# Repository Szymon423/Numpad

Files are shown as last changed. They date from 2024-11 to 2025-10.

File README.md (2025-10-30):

<div align="center">

# 🔢 Numpad

*A custom-designed numeric keypad project*

</div>

---

## 📖 About

This project is about designing my own Numpad.

> [!NOTE]  
> But not as good as existing solutions

I wanted to do this because I bought a keyboard without a numeric keypad. The project was on my to-do list, waiting until (I make it real) I bought a keyboard with a numeric keypad. Even though I'm the proud owner of a keyboard with a numeric keypad, I wanted to finish it.

---

## 🖼️ Let's have a look

<div align="center">

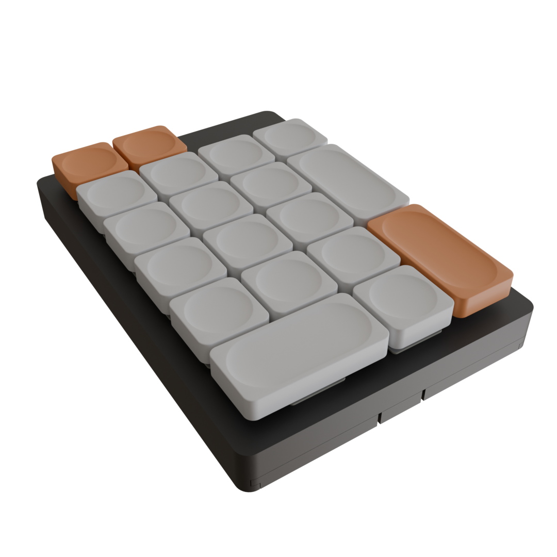
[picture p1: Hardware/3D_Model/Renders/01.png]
Main Render


</div>

---

## 🔧 Hardware

Hardware was designed in **KiCad** around the **RP2040** from Raspberry Pi. I like low-profile keyboards, thus I used **Gateron KS-33** switches with custom keycaps inspired by the **Logitech MX Keys**.

### Additional Renders

<div align="center">

<table>
  <tr>
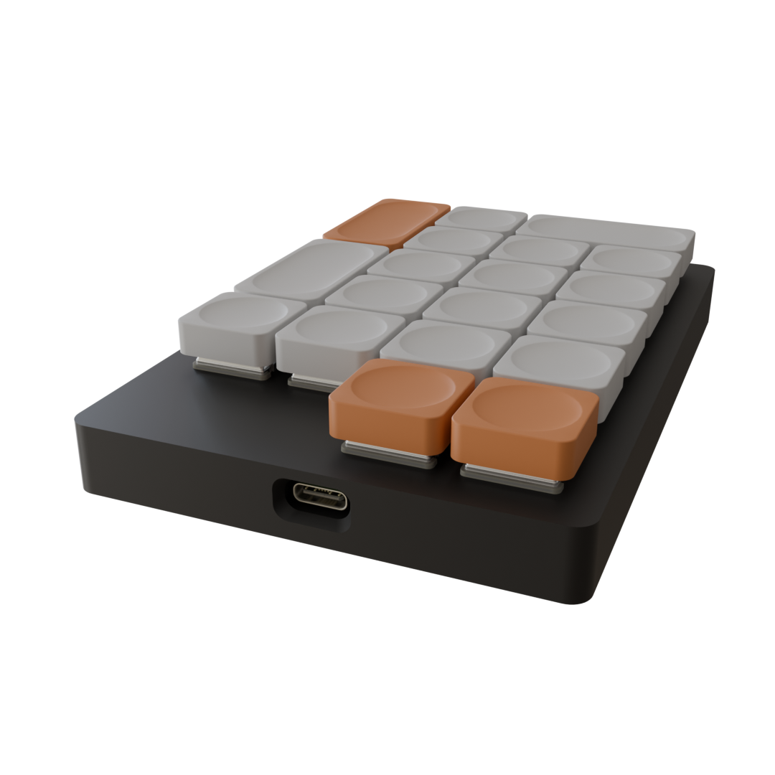
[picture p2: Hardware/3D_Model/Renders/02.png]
Render 02
    <td width="50%"></td>
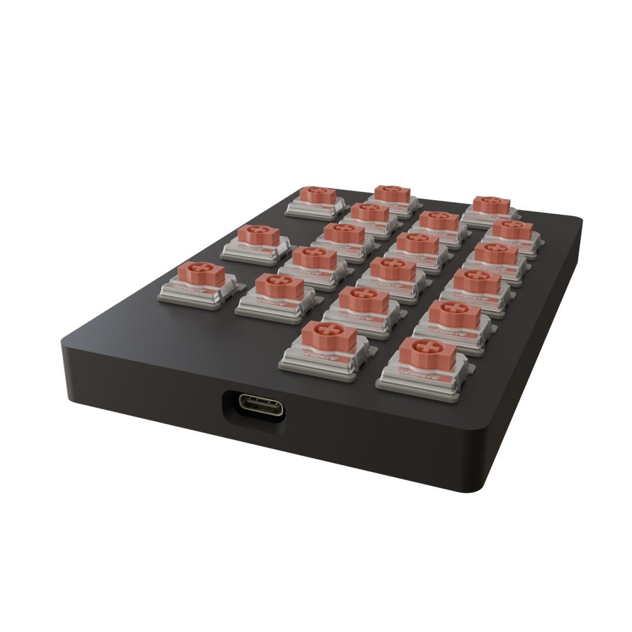
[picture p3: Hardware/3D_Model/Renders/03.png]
Render 03
    <td width="50%"></td>
  </tr>
  <tr>
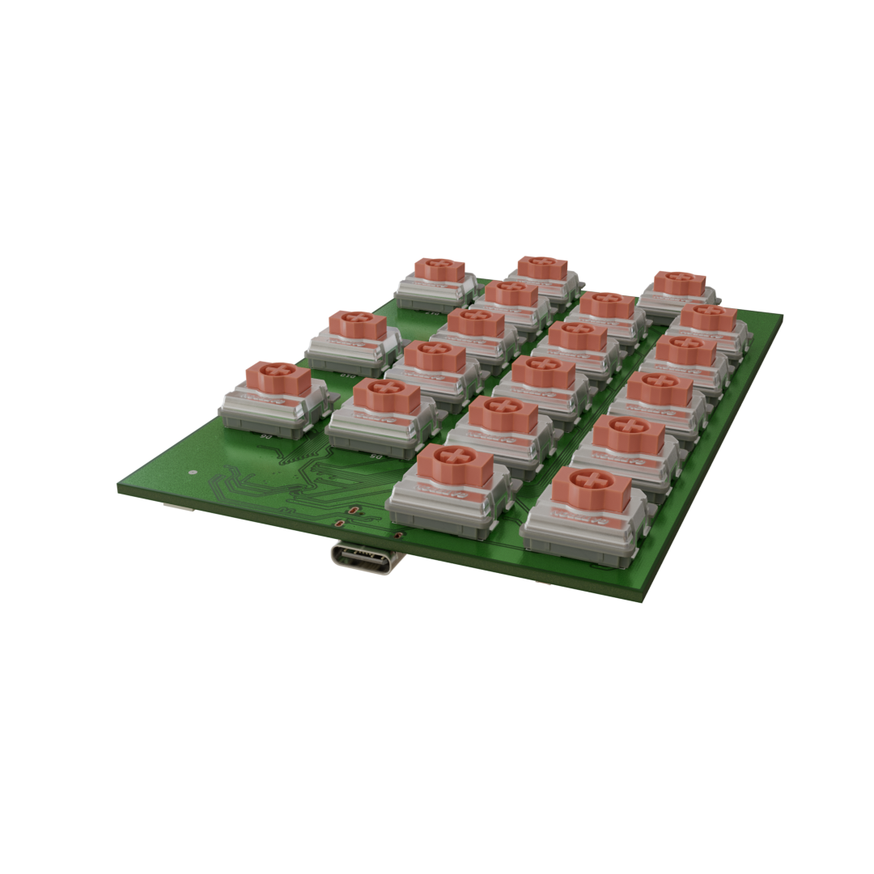
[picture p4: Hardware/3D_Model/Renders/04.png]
Render 04
    <td width="50%"></td>
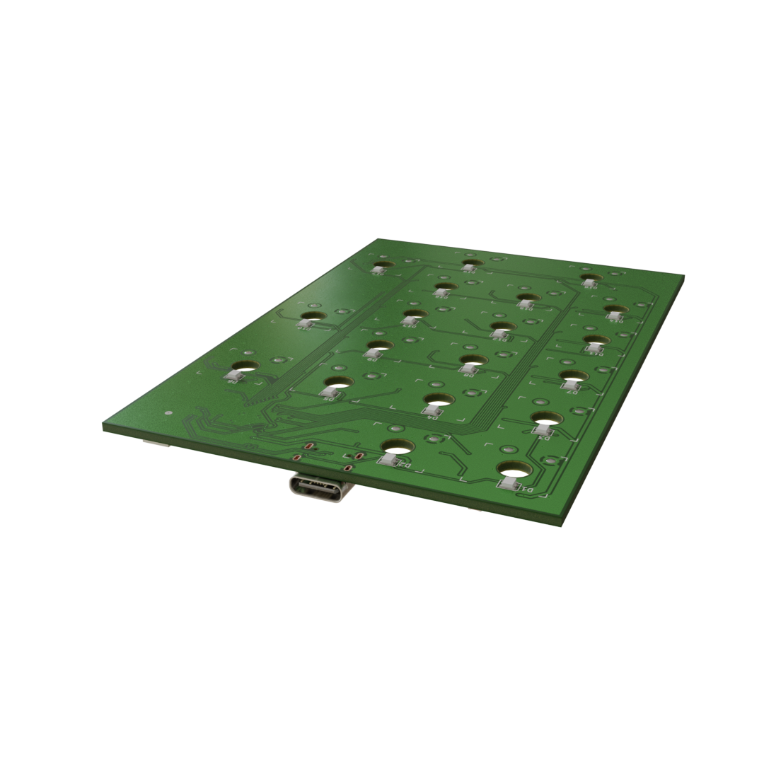
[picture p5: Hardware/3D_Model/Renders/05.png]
Render 05
    <td width="50%"></td>
  </tr>
</table>

</div>

---

## 💻 Software

Software is still in development. 🚧

---

<div align="center">

*Made because of lack of cool and cheap solutions along with ❤️ to tinkering*

</div>

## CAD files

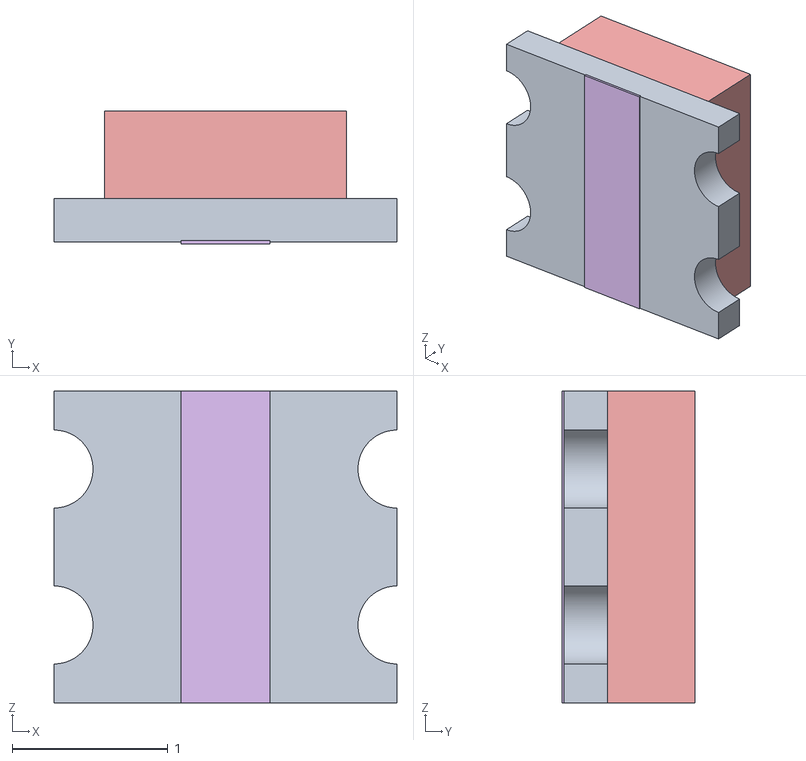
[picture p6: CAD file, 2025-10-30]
Hardware/3D_Model/Assets/WS2812C-2020.obj
2.20 x 0.85 x 2.00
obj1
obj2
obj3
obj4
obj5
obj6
obj7
obj8

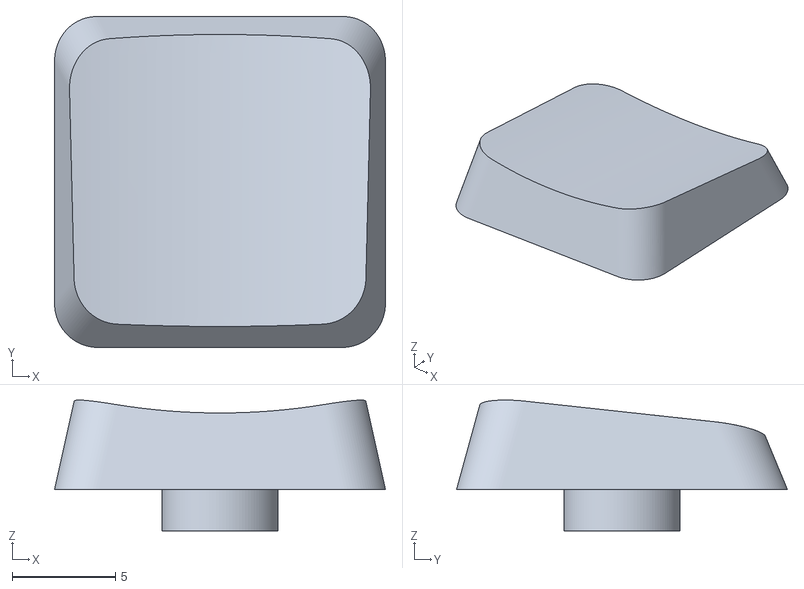
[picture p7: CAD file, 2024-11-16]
Hardware/3D_Model/Assets/Keycap-Low-Profile-Resin.stl
16.0 x 16.0 x 6.33

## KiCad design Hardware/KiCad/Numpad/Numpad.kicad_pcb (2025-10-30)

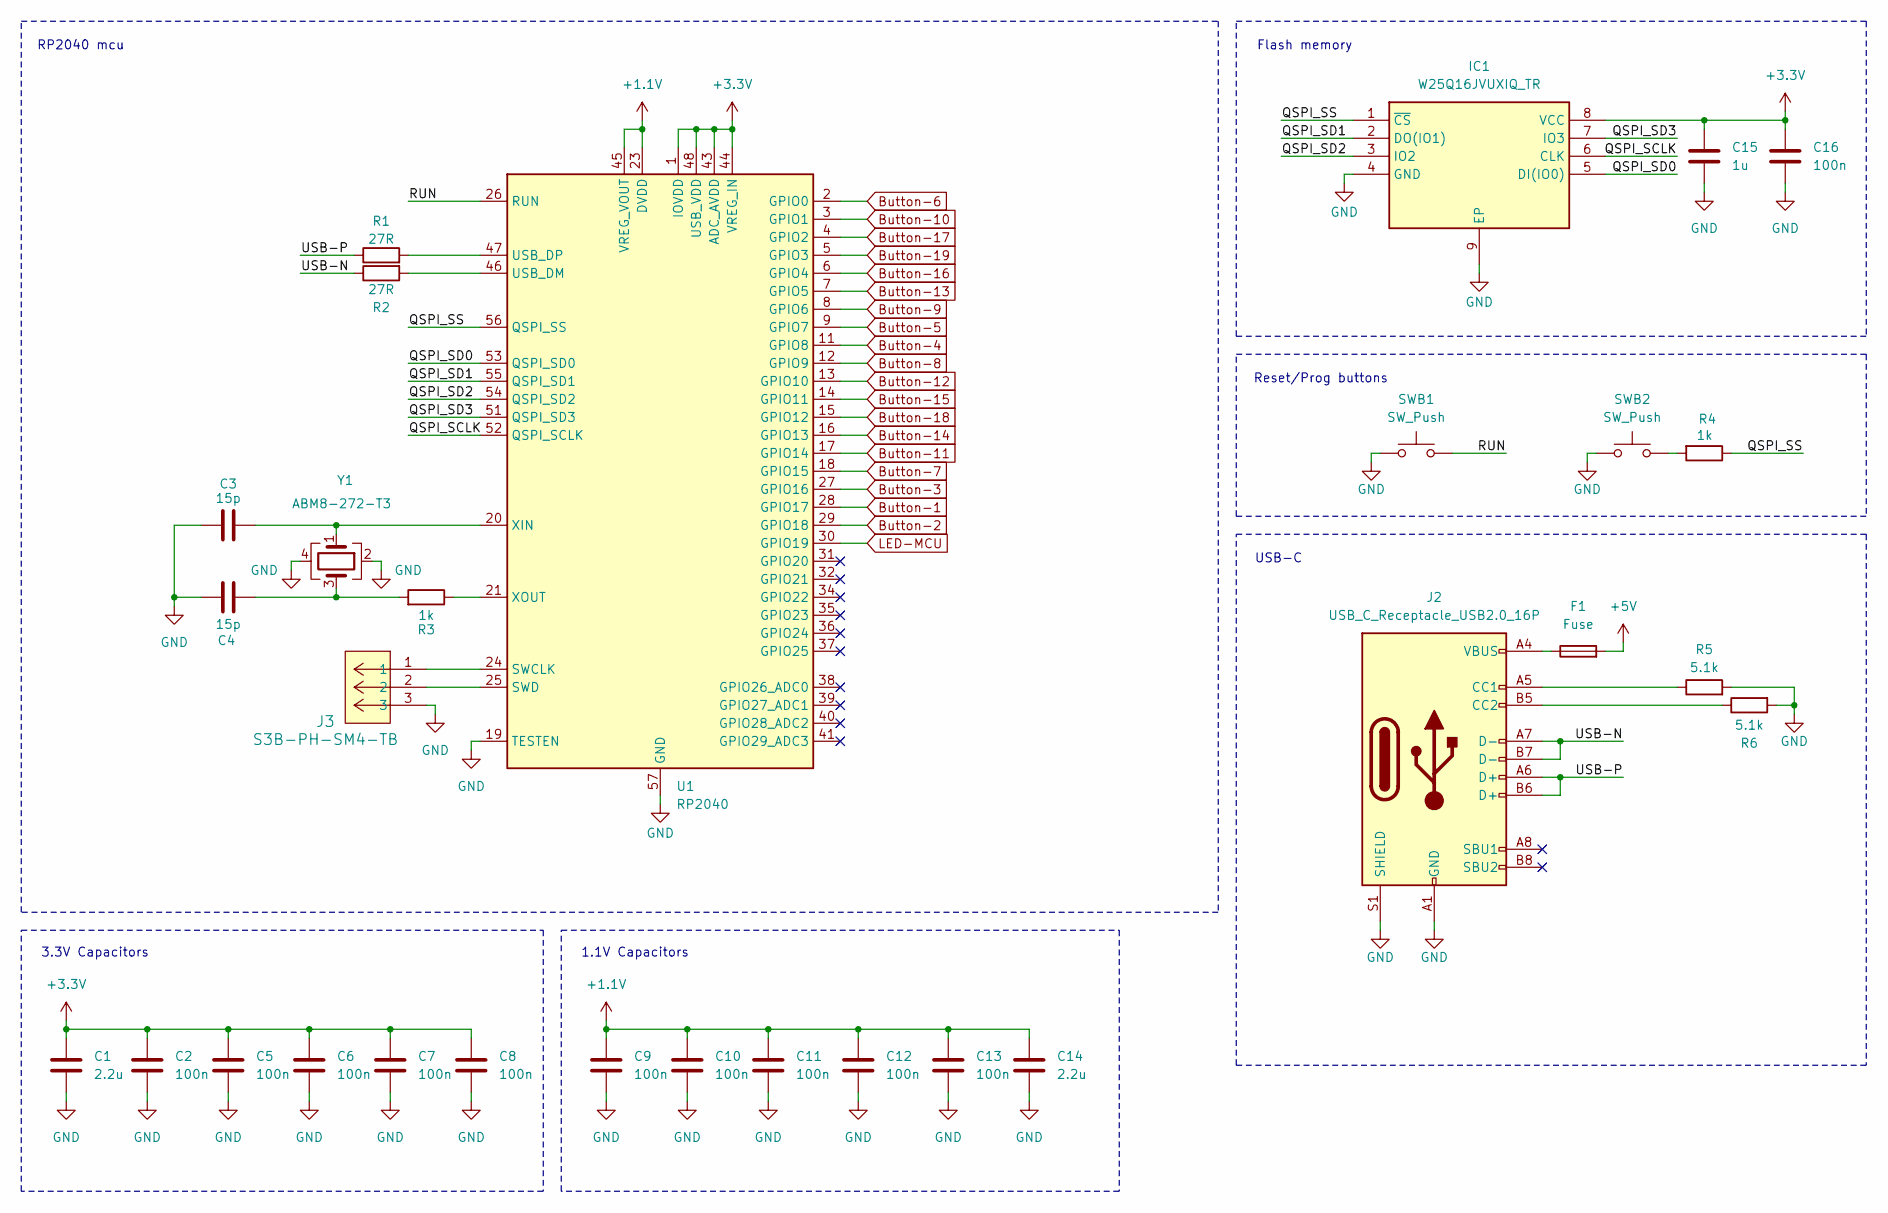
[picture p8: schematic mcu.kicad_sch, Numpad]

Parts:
C1, C14: 2.2u; C_0805_2012Metric
C2, C5, C6, C7, C8, C9, C10, C11, C12, C13, C16: 100n; C_0402_1005Metric
C3, C4: 15p; C_0402_1005Metric
C15: 1u; C_0805_2012Metric
F1: Fuse; Fuse_1206_3216Metric
IC1: W25Q16JVUXIQ_TR; Winbond_USON-8-1EP_3x2mm_P0.5mm_EP0.2x1.6mm; Manufacturer_Part_Number W25Q16JVUXIQ TR
J2: USB_C_Receptacle_USB2.0_16P; USB_C_Receptacle_GCT_USB4105-xx-A_16P_TopMnt_Horizontal
J3: S3B-PH-SM4-TB; CONN3_S3B-PH_JST
R1, R2: 27R; R_0402_1005Metric
R3, R4: 1k; R_0402_1005Metric
R5, R6: 5.1k; R_0603_1608Metric
SWB1, SWB2: SW_Push; SW_Tactile_SPST_NO_Straight_CK_PTS636Sx25SMTRLFS
U1: RP2040; QFN-56-1EP_7x7mm_P0.4mm_EP3.2x3.2mm_ThermalVias
Y1: ABM8-272-T3; Crystal_SMD_Abracon_ABM3B-4Pin_5.0x3.2mm

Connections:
+1.1V: C9.1, C10.1, C11.1, C12.1, C13.1, C14.1, U1.23 (DVDD), U1.45 (VREG_VOUT), U1.50 (DVDD)
+3.3V: C1.1, C2.1, C5.1, C6.1, C7.1, C8.1, C15.1, C16.1, IC1.8 (VCC), U1.1 (IOVDD), U1.10 (IOVDD), U1.22 (IOVDD), U1.33 (IOVDD), U1.42 (IOVDD), U1.43 (ADC_AVDD), U1.44 (VREG_IN), U1.48 (USB_VDD), U1.49 (IOVDD); also elsewhere on the board
+5V: F1.2; also elsewhere on the board
/Microcontroller/QSPI_SCLK: IC1.6 (CLK), U1.52 (QSPI_SCLK)
/Microcontroller/QSPI_SD0: IC1.5 (DI(IO0)), U1.53 (QSPI_SD0)
/Microcontroller/QSPI_SD1: IC1.2 (DO(IO1)), U1.55 (QSPI_SD1)
/Microcontroller/QSPI_SD2: IC1.3 (IO2), U1.54 (QSPI_SD2)
/Microcontroller/QSPI_SD3: IC1.7 (IO3), U1.51 (QSPI_SD3)
/Microcontroller/QSPI_SS: IC1.1 (~CS), R4.1, U1.56 (QSPI_SS)
/Microcontroller/RUN: SWB1.2, U1.26 (RUN)
/Microcontroller/USB-N: J2.A7 (D-), J2.B7 (D-), R2.1
/Microcontroller/USB-P: J2.A6 (D+), J2.B6 (D+), R1.1
Button-1: U1.28 (GPIO17); also elsewhere on the board
Button-2: U1.29 (GPIO18); also elsewhere on the board
Button-3: U1.27 (GPIO16); also elsewhere on the board
Button-4: U1.11 (GPIO8); also elsewhere on the board
Button-5: U1.9 (GPIO7); also elsewhere on the board
Button-6: U1.2 (GPIO0); also elsewhere on the board
Button-7: U1.18 (GPIO15); also elsewhere on the board
Button-8: U1.12 (GPIO9); also elsewhere on the board
Button-9: U1.8 (GPIO6); also elsewhere on the board
Button-10: U1.3 (GPIO1); also elsewhere on the board
Button-11: U1.17 (GPIO14); also elsewhere on the board
Button-12: U1.13 (GPIO10); also elsewhere on the board
Button-13: U1.7 (GPIO5); also elsewhere on the board
Button-14: U1.16 (GPIO13); also elsewhere on the board
Button-15: U1.14 (GPIO11); also elsewhere on the board
Button-16: U1.6 (GPIO4); also elsewhere on the board
Button-17: U1.4 (GPIO2); also elsewhere on the board
Button-18: U1.15 (GPIO12); also elsewhere on the board
Button-19: U1.5 (GPIO3); also elsewhere on the board
GND: C1.2, C2.2, C3.1, C4.1, C5.2, C6.2, C7.2, C8.2, C9.2, C10.2, C11.2, C12.2, C13.2, C14.2, C15.2, C16.2, IC1.4 (GND), IC1.9 (EP), J2.A1 (GND), J2.A12 (GND), J2.B1 (GND), J2.B12 (GND), J2.S1 (SHIELD), J3.3, R5.2, R6.2, SWB1.1, SWB2.1, U1.19 (TESTEN), U1.57 (GND), Y1.2, Y1.4; also elsewhere on the board
LED-MCU: U1.30 (GPIO19); also elsewhere on the board
unnamed: C4.2, R3.2, Y1.3
unnamed: F1.1, J2.A4 (VBUS), J2.A9 (VBUS), J2.B4 (VBUS), J2.B9 (VBUS)
unnamed: J2.A5 (CC1), R5.1
unnamed: J2.B5 (CC2), R6.1
unnamed: R4.2, SWB2.2
unnamed: J3.1, U1.24 (SWCLK)
unnamed: J3.2, U1.25 (SWD)
unnamed: R2.2, U1.46 (USB_DM)
unnamed: R1.2, U1.47 (USB_DP)
unnamed: C3.2, U1.20 (XIN), Y1.1
unnamed: R3.1, U1.21 (XOUT)

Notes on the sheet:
RP2040 mcu
Flash memory
3.3V Capacitors
Reset/Prog buttons
1.1V Capacitors
USB-C

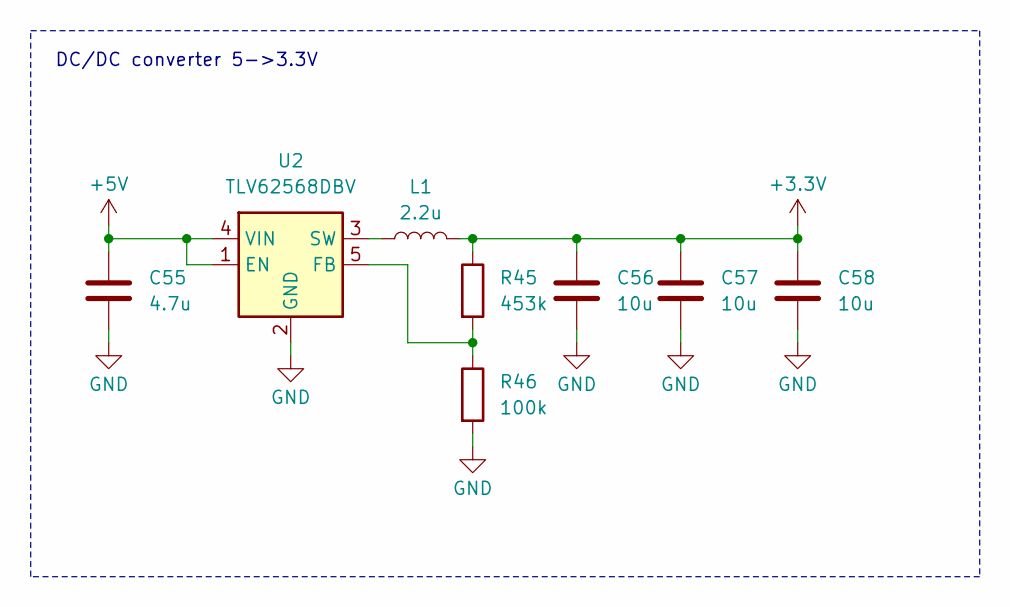
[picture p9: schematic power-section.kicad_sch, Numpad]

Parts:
C55: 4.7u; C_0805_2012Metric
C56, C57, C58: 10u; C_0805_2012Metric
L1: 2.2u; L_Ferrocore_DLG-0504
R45: 453k; R_0603_1608Metric
R46: 100k; R_0603_1608Metric
U2: TLV62568DBV; SOT-23-5

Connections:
+3.3V: C56.2, C57.2, C58.2, L1.2, R45.1; also elsewhere on the board
+5V: C55.2, U2.1 (EN), U2.4 (VIN); also elsewhere on the board
GND: C55.1, C56.1, C57.1, C58.1, R46.2, U2.2 (GND); also elsewhere on the board
unnamed: R45.2, R46.1, U2.5 (FB)
unnamed: L1.1, U2.3 (SW)

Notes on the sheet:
DC/DC converter 5->3.3V

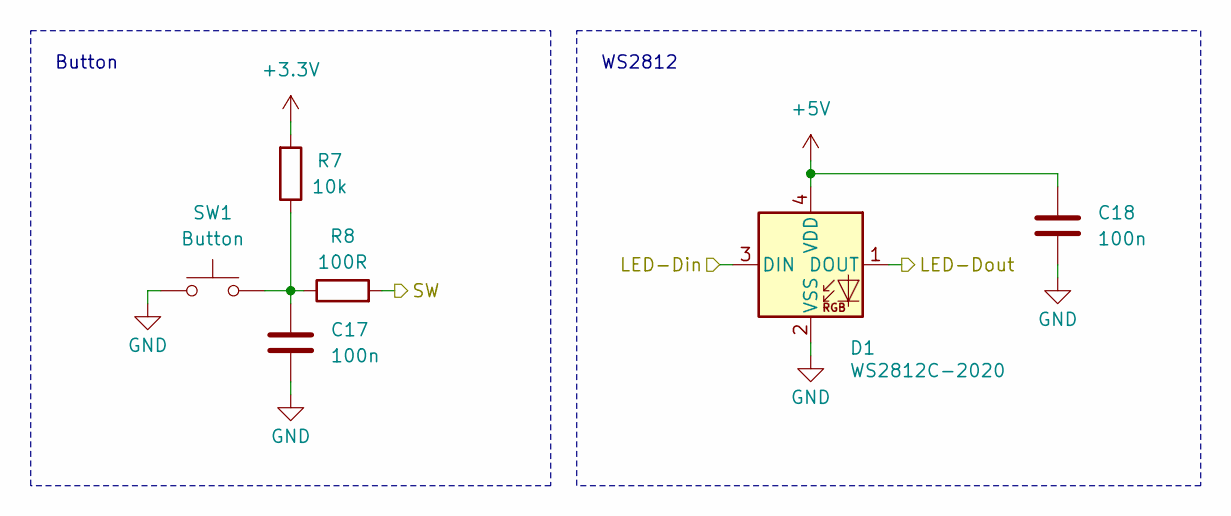
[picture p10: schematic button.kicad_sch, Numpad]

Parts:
C17, C18: 100n; C_0603_1608Metric
D1: WS2812C-2020; LED_WS2812B-2020_PLCC4_2.0x2.0mm
R7: 10k; R_0603_1608Metric
R8: 100R; R_0603_1608Metric
SW1: Button; SW_Gateron_LowProfile_THT

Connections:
+3.3V: R7.2; also elsewhere on the board
+5V: C18.1, D1.4 (VDD); also elsewhere on the board
/Buttons/Button1/LED-Din: D1.3 (DIN); also elsewhere on the board
/Buttons/Button1/LED-Dout: D1.1 (DOUT); also elsewhere on the board
Button-1: R8.2; also elsewhere on the board
GND: C17.2, C18.2, D1.2 (VSS), SW1.1; also elsewhere on the board
unnamed: C17.1, R7.1, R8.1, SW1.2

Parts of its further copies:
C19, C20, C21, C22, C23, C24, C25, C26, C27, C28, C29, C30, C31, C32, C33, C34, C35, C36, C37, C38, C39, C40, C41, C42, C43, C44, C45, C46, C47, C48, C49, C50, C51, C52, C53, C54: 100n; C_0603_1608Metric
D2, D3, D4, D5, D6, D7, D8, D9, D10, D11, D12, D13, D14, D15, D16, D17, D18, D19: WS2812C-2020; LED_WS2812B-2020_PLCC4_2.0x2.0mm
R9, R11, R13, R15, R17, R19, R21, R23, R25, R27, R29, R31, R33, R35, R37, R39, R41, R43: 10k; R_0603_1608Metric
R10, R12, R14, R16, R18, R20, R22, R24, R26, R28, R30, R32, R34, R36, R38, R40, R42, R44: 100R; R_0603_1608Metric
SW2, SW3, SW4, SW5, SW6, SW7, SW8, SW9, SW10, SW11, SW12, SW13, SW14, SW15, SW16, SW17, SW18, SW19: Button; SW_Gateron_LowProfile_THT

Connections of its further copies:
+3.3V: R9.2, R11.2, R13.2, R15.2, R17.2, R19.2, R21.2, R23.2, R25.2, R27.2, R29.2, R31.2, R33.2, R35.2, R37.2, R39.2, R41.2, R43.2; also elsewhere on the board
+5V: C20.1, C22.1, C24.1, C26.1, C28.1, C30.1, C32.1, C34.1, C36.1, C38.1, C40.1, C42.1, C44.1, C46.1, C48.1, C50.1, C52.1, C54.1, D2.4 (VDD), D3.4 (VDD), D4.4 (VDD), D5.4 (VDD), D6.4 (VDD), D7.4 (VDD), D8.4 (VDD), D9.4 (VDD), D10.4 (VDD), D11.4 (VDD), D12.4 (VDD), D13.4 (VDD), D14.4 (VDD), D15.4 (VDD), D16.4 (VDD), D17.4 (VDD), D18.4 (VDD), D19.4 (VDD); also elsewhere on the board
/Buttons/Button1/LED-Din: D2.1 (DOUT); also elsewhere on the board
/Buttons/Button1/LED-Dout: D3.3 (DIN); also elsewhere on the board
/Buttons/Button3/LED-Dout: D3.1 (DOUT), D4.3 (DIN)
/Buttons/Button4/LED-Dout: D4.1 (DOUT), D5.3 (DIN)
/Buttons/Button5/LED-Dout: D5.1 (DOUT), D6.3 (DIN)
/Buttons/Button6/LED-Dout: D6.1 (DOUT), D9.3 (DIN)
/Buttons/Button7/LED-Din: D7.3 (DIN), D8.1 (DOUT)
/Buttons/Button8/LED-Din: D8.3 (DIN), D9.1 (DOUT)
/Buttons/Button10/LED-Din: D10.3 (DIN), D13.1 (DOUT)
/Buttons/Button10/LED-Dout: D10.1 (DOUT), D16.3 (DIN)
/Buttons/Button11/LED-Din: D7.1 (DOUT), D11.3 (DIN)
/Buttons/Button11/LED-Dout: D11.1 (DOUT), D12.3 (DIN)
/Buttons/Button12/LED-Dout: D12.1 (DOUT), D13.3 (DIN)
/Buttons/Button14/LED-Din: D14.3 (DIN), D15.1 (DOUT)
/Buttons/Button14/LED-Dout: D14.1 (DOUT), D18.3 (DIN)
/Buttons/Button15/LED-Din: D15.3 (DIN), D16.1 (DOUT)
/Buttons/Button17/LED-Din: D17.3 (DIN), D19.1 (DOUT)
/Buttons/Button17/LED-Dout: D17.1 (DOUT)
/Buttons/Button18/LED-Dout: D18.1 (DOUT), D19.3 (DIN)
Button-2: R10.2; also elsewhere on the board
Button-3: R12.2; also elsewhere on the board
Button-4: R14.2; also elsewhere on the board
Button-5: R16.2; also elsewhere on the board
Button-6: R18.2; also elsewhere on the board
Button-7: R20.2; also elsewhere on the board
Button-8: R22.2; also elsewhere on the board
Button-9: R24.2; also elsewhere on the board
Button-10: R26.2; also elsewhere on the board
Button-11: R28.2; also elsewhere on the board
Button-12: R30.2; also elsewhere on the board
Button-13: R32.2; also elsewhere on the board
Button-14: R34.2; also elsewhere on the board
Button-15: R36.2; also elsewhere on the board
Button-16: R38.2; also elsewhere on the board
Button-17: R40.2; also elsewhere on the board
Button-18: R42.2; also elsewhere on the board
Button-19: R44.2; also elsewhere on the board
GND: C19.2, C20.2, C21.2, C22.2, C23.2, C24.2, C25.2, C26.2, C27.2, C28.2, C29.2, C30.2, C31.2, C32.2, C33.2, C34.2, C35.2, C36.2, C37.2, C38.2, C39.2, C40.2, C41.2, C42.2, C43.2, C44.2, C45.2, C46.2, C47.2, C48.2, C49.2, C50.2, C51.2, C52.2, C53.2, C54.2, D2.2 (VSS), D3.2 (VSS), D4.2 (VSS), D5.2 (VSS), D6.2 (VSS), D7.2 (VSS), D8.2 (VSS), D9.2 (VSS), D10.2 (VSS), D11.2 (VSS), D12.2 (VSS), D13.2 (VSS), D14.2 (VSS), D15.2 (VSS), D16.2 (VSS), D17.2 (VSS), D18.2 (VSS), D19.2 (VSS), SW2.1, SW3.1, SW4.1, SW5.1, SW6.1, SW7.1, SW8.1, SW9.1, SW10.1, SW11.1, SW12.1, SW13.1, SW14.1, SW15.1, SW16.1, SW17.1, SW18.1, SW19.1; also elsewhere on the board
LED-MCU: D2.3 (DIN); also elsewhere on the board
unnamed: C19.1, R9.1, R10.1, SW2.2
unnamed: C21.1, R11.1, R12.1, SW3.2
unnamed: C23.1, R13.1, R14.1, SW4.2
unnamed: C25.1, R15.1, R16.1, SW5.2
unnamed: C27.1, R17.1, R18.1, SW6.2
unnamed: C29.1, R19.1, R20.1, SW7.2
unnamed: C31.1, R21.1, R22.1, SW8.2
unnamed: C33.1, R23.1, R24.1, SW9.2
unnamed: C35.1, R25.1, R26.1, SW10.2
unnamed: C37.1, R27.1, R28.1, SW11.2
unnamed: C39.1, R29.1, R30.1, SW12.2
unnamed: C41.1, R31.1, R32.1, SW13.2
unnamed: C43.1, R33.1, R34.1, SW14.2
unnamed: C45.1, R35.1, R36.1, SW15.2
unnamed: C47.1, R37.1, R38.1, SW16.2
unnamed: C49.1, R39.1, R40.1, SW17.2
unnamed: C51.1, R41.1, R42.1, SW18.2
unnamed: C53.1, R43.1, R44.1, SW19.2

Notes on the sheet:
Button
WS2812

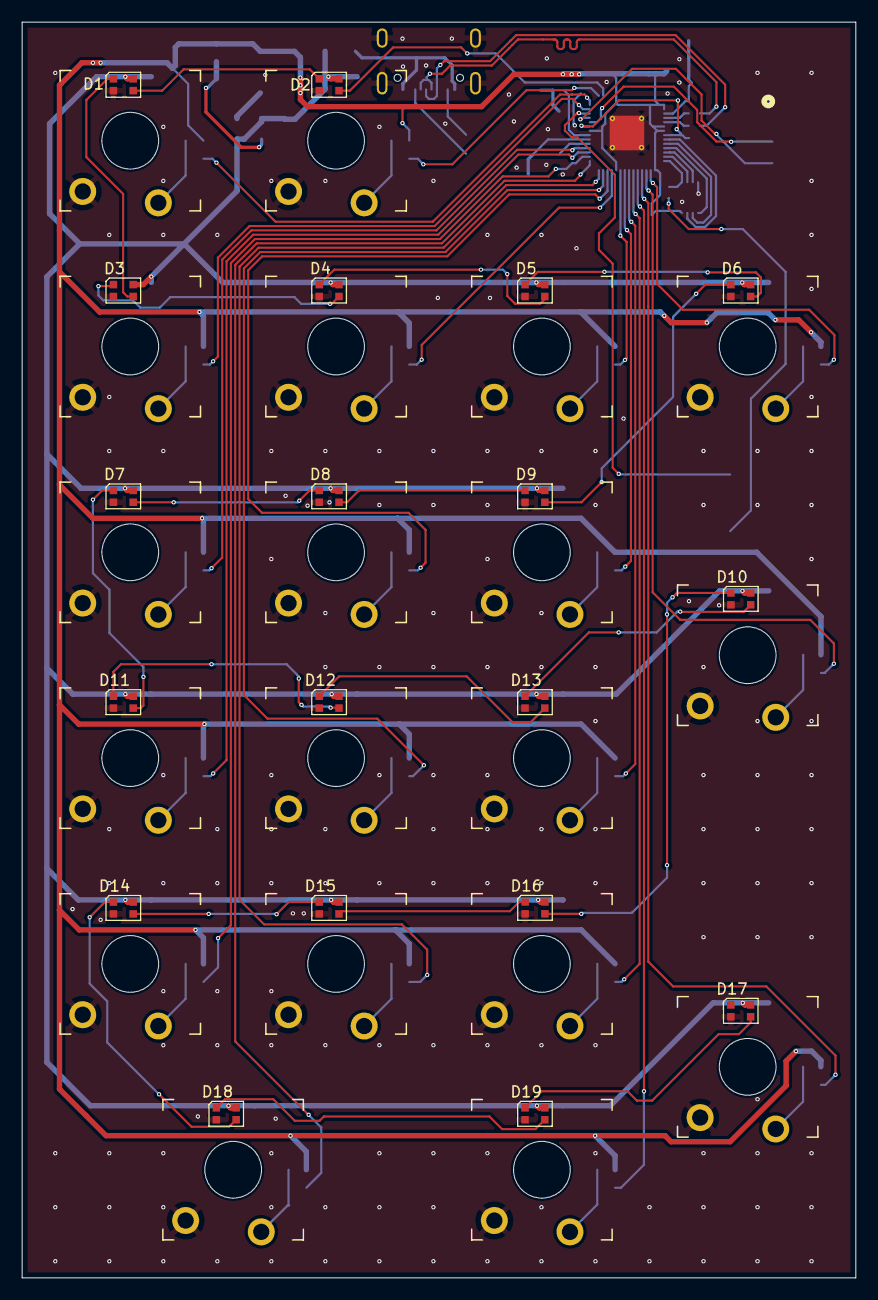
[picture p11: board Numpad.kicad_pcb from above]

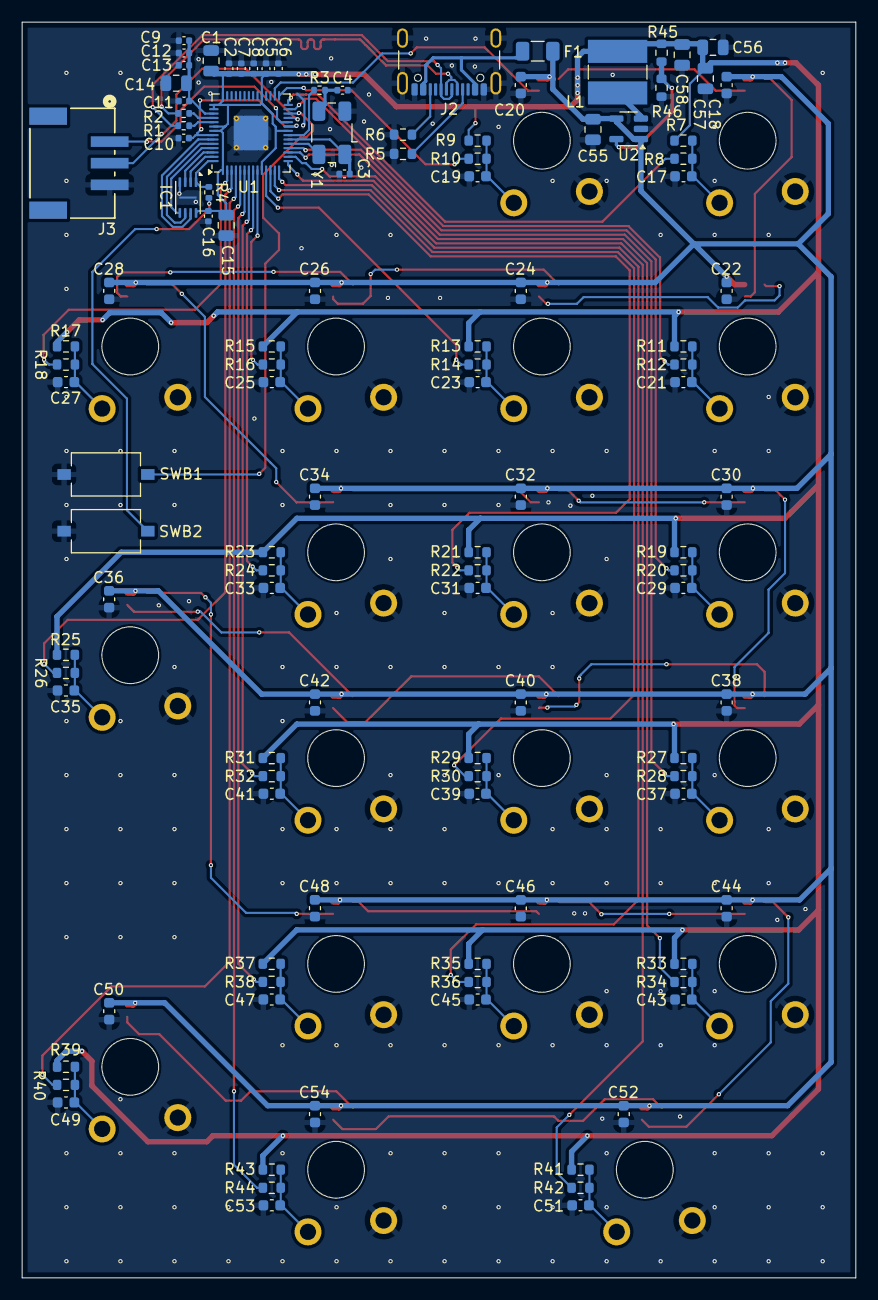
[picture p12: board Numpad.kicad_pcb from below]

Board: 2 copper layers, 77.2 x 116.2 mm, 152 parts (114 on the bottom side), 83 nets.

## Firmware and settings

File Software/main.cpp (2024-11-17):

#include "pico/stdio.h"
#include "pico/time.h"
#include "bsp/board_api.h"
#include <tusb.h>
#include "hid.hpp"
#include "pixels.hpp"

int main() {
	// init board and peripherials
	board_init();

	// init device stack on configured roothub port
  	tud_init(BOARD_TUD_RHPORT);

	while (true) {
		// TinyUSB device task
		tud_task();
		
		// LEDs task
		LED::Pixels::Handler();
		
		// HID task
		hid_task();
	}
};

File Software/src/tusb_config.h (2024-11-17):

/*
 * The MIT License (MIT)
 *
 * Copyright (c) 2019 Ha Thach (tinyusb.org)
 *
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
 */

#ifndef _TUSB_CONFIG_H_
#define _TUSB_CONFIG_H_

#ifdef __cplusplus
extern "C"
{
#endif

//--------------------------------------------------------------------+
// Board Specific Configuration
//--------------------------------------------------------------------+

// RHPort number used for device can be defined by board.mk, default to port 0
#ifndef BOARD_TUD_RHPORT
#define BOARD_TUD_RHPORT 0
#endif

// RHPort max operational speed can defined by board.mk
#ifndef BOARD_TUD_MAX_SPEED
#define BOARD_TUD_MAX_SPEED OPT_MODE_DEFAULT_SPEED
#endif

//--------------------------------------------------------------------
// COMMON CONFIGURATION
//--------------------------------------------------------------------

// defined by compiler flags for flexibility
#ifndef CFG_TUSB_MCU
#error CFG_TUSB_MCU must be defined
#endif

#ifndef CFG_TUSB_OS
#define CFG_TUSB_OS OPT_OS_NONE
#endif

#ifndef CFG_TUSB_DEBUG
#define CFG_TUSB_DEBUG 0
#endif

// Enable Device stack
#define CFG_TUD_ENABLED 1

// Default is max speed that hardware controller could support with on-chip PHY
#define CFG_TUD_MAX_SPEED BOARD_TUD_MAX_SPEED

/* USB DMA on some MCUs can only access a specific SRAM region with restriction on alignment.
 * Tinyusb use follows macros to declare transferring memory so that they can be put
 * into those specific section.
 * e.g
 * - CFG_TUSB_MEM SECTION : __attribute__ (( section(".usb_ram") ))
 * - CFG_TUSB_MEM_ALIGN   : __attribute__ ((aligned(4)))
 */
#ifndef CFG_TUSB_MEM_SECTION
#define CFG_TUSB_MEM_SECTION
#endif

#ifndef CFG_TUSB_MEM_ALIGN
#define CFG_TUSB_MEM_ALIGN __attribute__((aligned(4)))
#endif

	//--------------------------------------------------------------------
	// DEVICE CONFIGURATION
	//--------------------------------------------------------------------

#ifndef CFG_TUD_ENDPOINT0_SIZE
#define CFG_TUD_ENDPOINT0_SIZE 64
#endif

//------------- CLASS -------------//
#define CFG_TUD_HID 1
#define CFG_TUD_CDC 0
#define CFG_TUD_MSC 0
#define CFG_TUD_MIDI 0
#define CFG_TUD_VENDOR 0

// HID buffer size Should be sufficient to hold ID (if any) + Data
#define CFG_TUD_HID_EP_BUFSIZE 16

#ifdef __cplusplus
}
#endif

#endif /* _TUSB_CONFIG_H_ */

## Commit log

2024-11-16 added hardware stuff
    [EC10E1220503.obj, Gateron-ks-33.stl, Keycap-Low-Profile-Resin.stl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]
2024-11-17 added something which will not compile, and not work but it is a good start into hid
    [main.cpp, tusb_config.h]
2025-10-30 A little update on hardware
    [EC10E1220503.obj, Gateron-ks-33.stl, Keycap-Low-Profile-Resin.stl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]
